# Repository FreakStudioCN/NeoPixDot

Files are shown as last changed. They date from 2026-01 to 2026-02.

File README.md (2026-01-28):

# NeoPixDot 光链像素产品说明文档

# **一、产品简介**

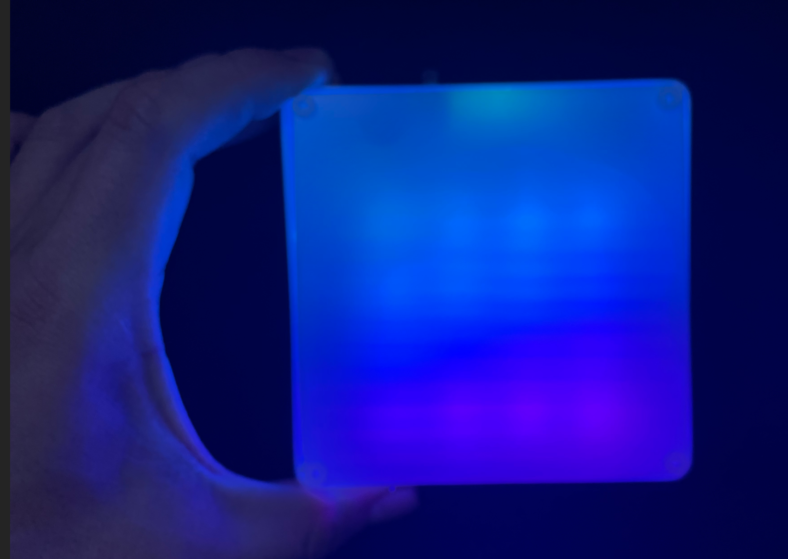
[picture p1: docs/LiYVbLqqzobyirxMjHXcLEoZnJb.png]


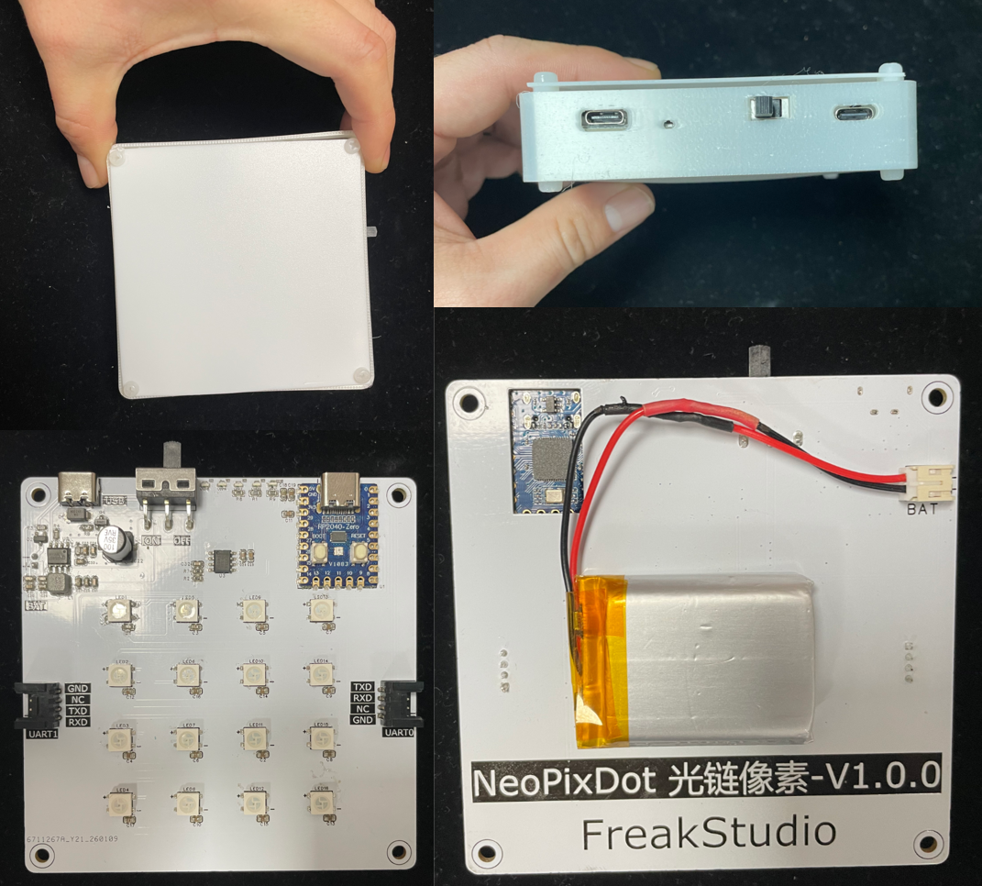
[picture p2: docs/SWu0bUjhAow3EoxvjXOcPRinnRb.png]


一款带独立供电系统的级联式 WS2812 像素模拟模块，专为解决 WS2812 协议长距离/大尺寸传输不稳定问题设计，支持脱线独立工作，可级联拼接成超大尺寸 WS2812 显示屏幕。

**仓库地址：[https://github.com/FreakStudioCN/NeoPixDot](https://github.com/FreakStudioCN/NeoPixDot)**

# **二、核心特性**

## **2.1 硬件特性**

- **主控核心**：RP2040 系列芯片，高性能且适配 MicroPython 开发
- **显示单元**：4x4 矩阵 WS2812 RGB 灯，搭配均光膜呈现“单个像素点”视觉效果
- **供电系统**：板载 IP5407 充放电单元 + 锂电池，支持 USB 充电/电池供电自动切换
- **级联设计**：双串口按“移位传输”逻辑级联，支持多模块拼接扩展

## **2.2 软件特性**

- **UART 数据处理**：解析 RGB 数据控制 WS2812 灯带，自动转发剩余数据至下一级模块
- **电池监测**：ADC 采集电池电压 + 滑动滤波算法，低电压时红灯闪烁告警并禁用 UART 控灯
- **稳定保障**：集成看门狗（WDT）定时喂狗防程序卡死，环形缓冲区 + 中断安全调度确保 UART 数据传输稳定
- **灯效支持**：正常电压下自动执行彩虹流动灯效，低电压触发红灯闪烁告警
- **调试友好**：可配置调试打印开关，计时装饰器辅助性能分析

# **三、硬件说明**

# **四、软件说明**

## **4.1 核心功能逻辑**

1. **UART 级联传输**：主控发送全量像素数据，模块解析自身 RGB 信息后，转发剩余数据至下一级
2. **电池电压监测**：100ms 周期采样电压，5 次滑动滤波去噪，低电压（3.4V）时红灯闪烁，禁用 UART 控灯；电压恢复后自动解除限制
3. **看门狗保障**：5 秒超时看门狗，1 秒周期定时喂狗 + 主循环喂狗，防止程序卡死
4. **灯效控制**：上电检测电压正常则执行彩虹流动灯效，低电压触发红灯闪烁，支持 UART 解析 RGB 数据实时控灯

## **4.2 代码关键模块**

- `RingBuffer`：环形缓冲区，解决 UART 数据接收满/空歧义问题，保障中断上下文数据安全
- `read_battery_adc`：电池电压采样 + 滑动滤波，提升电压检测稳定性
- `uart_idle_callback`：UART 空闲中断回调，接收数据并调度处理逻辑
- `rainbow_flow`：彩虹流动灯效实现，长操作前手动喂狗避免看门狗超时
- `wdt_feed_callback`：看门狗喂狗回调，定时重置超时计数器

## **4.3 文件功能介绍**

| 文件名 | 核心功能说明 |
| --- | --- |
| config.py | 全局配置中心，定义所有可配置参数（波特率、ADC 阈值、灯效参数、缓冲区大小等），统一管理常量和全局变量 |
| ring_buffer.py | 实现中断安全的环形缓冲区类，解决 UART 中断接收数据的缓存问题，预留 1 字节避免满 / 空状态歧义 |
| utils.py | 通用工具函数封装，包含调试打印（可控开关）、函数计时装饰器（辅助性能分析） |
| core_protected.py | 核心业务逻辑实现，涵盖 WS2812 灯效控制、电池电压采样 / 滤波、UART 数据解析 / 转发、看门狗喂狗、中断回调等 |
| main.py | 程序入口，完成初始化（定时器 / UART / 看门狗）、上电电压检测、主循环（电压监测 / 状态切换 / 喂狗） |
| pico_mpy_uploader.py | 编译 & 上传工具，自动将非 main.py 文件编译为 mpy（节省闪存 + 提升执行效率），通过 mpremote 上传至 Pico |

# **五、使用方法**

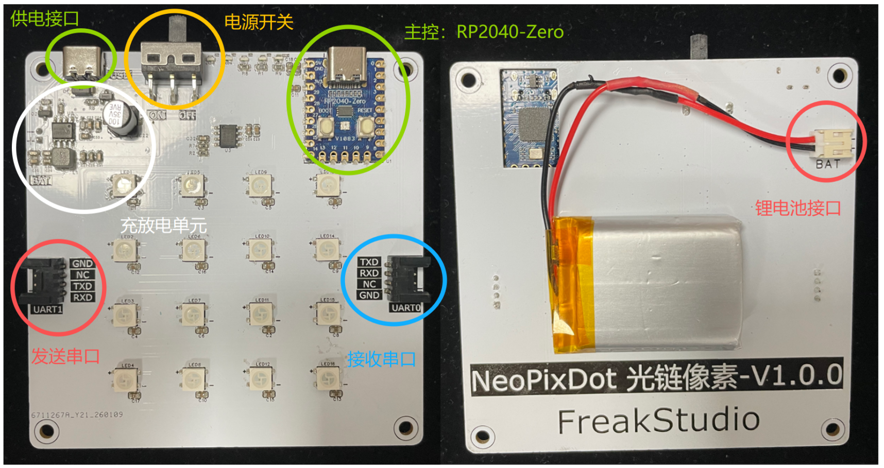
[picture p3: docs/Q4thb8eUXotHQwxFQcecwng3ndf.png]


## **5.1 供电**

- USB 充电：通过 USB 接口为锂电池充电，IP5407 自动管理充放电
- 电池供电：脱线状态下由锂电池供电，支持独立工作

正常上电情况下，有彩虹效果：

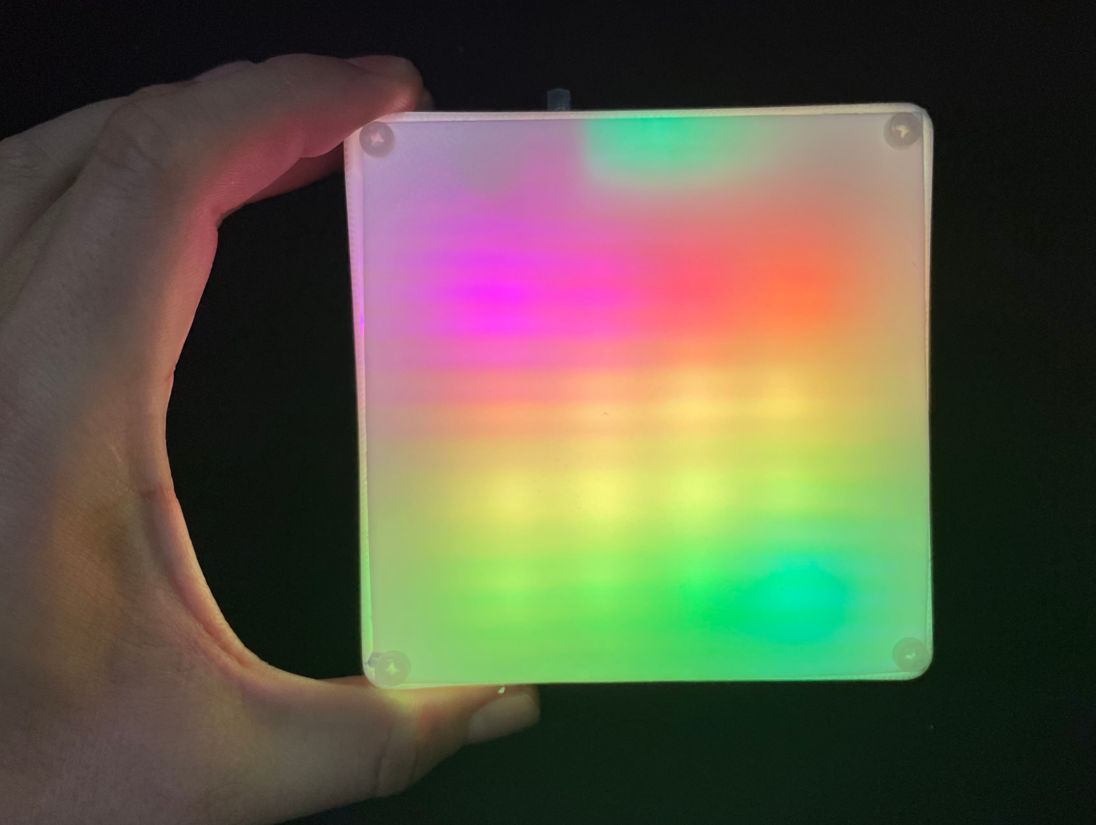
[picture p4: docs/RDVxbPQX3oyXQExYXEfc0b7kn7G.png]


**若是电量不足，则整个装置红灯闪烁。**

## **5.2 模块级联**

- 将前一级模块的 UART 转发口（UART1）连接至下一级的 UART 接收口（UART0）
- 主控发送全量像素数据，每个模块自动解析自身 RGB 数据，转发剩余数据至下一级

## **5.3 数据传输**

- UART 波特率：115200
- 数据格式：前 3 字节为当前模块 RGB 值，剩余字节为下一级模块数据
- 示例：发送 `0xFF000000FF00`，第一个模块显示红色，第二个模块显示绿色

# **六、注意事项**

1. 电池低电压阈值为 3.4V，低电时请及时充电，避免损坏电池
2. 调试模式可通过 `DEBUG_ENABLE` 开关开启/关闭，上线建议关闭以节省资源
3. 长耗时操作（如彩虹灯效、上电电压检测）会手动喂狗，避免看门狗超时重启

# 七、仓库文件介绍

# 版本记录

| **版本号** | **修改人员** | **时间** | **内容** |
| --- | --- | --- | --- |
| v1.0 | 李子圣 | 2026/01/28 | 初始化文档。 |
| | | | |
| | | | |
| | | | |

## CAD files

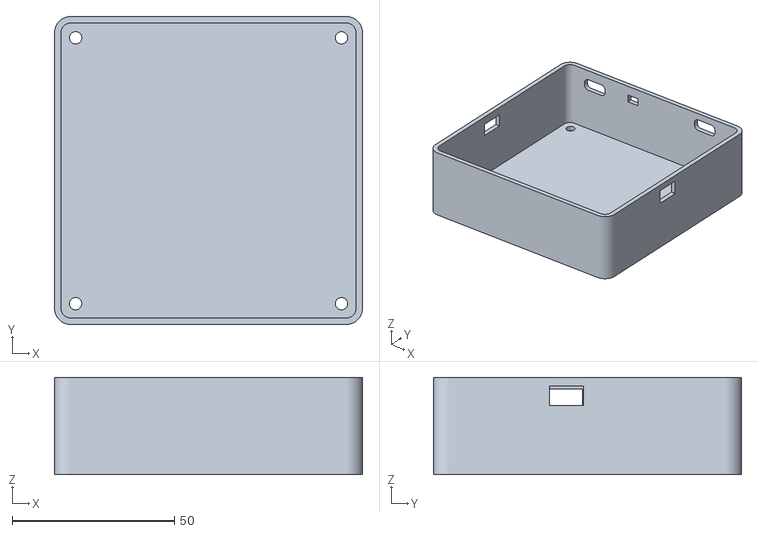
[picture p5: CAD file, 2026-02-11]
hardware/3DShell_3DShell_PCB_B.stl
95.0 x 95.0 x 30.0

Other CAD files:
hardware/DXF_LDP-ACP.SLDPRT
hardware/DXF_LDP-ACP.dxf

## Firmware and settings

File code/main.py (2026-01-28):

# Python env   : MicroPython v1.27
# -*- coding: utf-8 -*-
# @Time    : 2026/1/27 上午10:51
# @Author  : 李清水
# @File    : main.py
# @Description : 实现 UART 解析 RGB 控制 WS2812 并转发数据，
#                ADC 滑动滤波监测电池电压（低电告警禁 UART 控灯），集成 WDT 防卡死，通过环形缓冲区、中断调度保障运行稳定。

# ======================================== 导入相关模块 =========================================

from machine import UART, Pin, disable_irq, enable_irq, ADC, Timer, WDT
import time
import neopixel
import micropython
from config import *
from utils import debug_print, timed_function
from core_protected import *

# ======================================== 全局变量 ============================================

# ======================================== 功能函数 ============================================

# ======================================== 自定义类 ============================================

# ======================================== 初始化配置 ==========================================

# 分配紧急异常缓冲区（防止中断中出现异常时无法打印信息）
micropython.alloc_emergency_exception_buf(100)

# 初始化电池电压采集定时器（100ms一次）
battery_timer = Timer(-1)
battery_timer.init(period=BATTERY_TIMER_PERIOD, mode=Timer.PERIODIC, callback=read_battery_adc)

# 初始化UART接收和转发端口
uart_recv = UART(0, baudrate=BAUDRATE, tx=Pin(0), rx=Pin(1), bits=8, parity=None, stop=1)
# 配置UART空闲中断（接收完成后触发）
uart_recv.irq(handler=uart_idle_callback, trigger=UART.IRQ_RXIDLE, hard=False)
debug_print("✅ WDT initialized with timeout: %d seconds" % (WDT_TIMEOUT / 1000))

# 初始化喂狗软件定时器（1秒周期自动喂狗）
wdt_feed_timer = Timer(-1)
wdt_feed_timer.init(period=WDT_FEED_PERIOD, mode=Timer.PERIODIC, callback=wdt_feed_callback)
debug_print("✅ WDT feed timer initialized with period: %d seconds" % (WDT_FEED_PERIOD / 1000))

# ========================================  主程序  ===========================================

if __name__ == "__main__":
    debug_print("=== UART+WS2812+Battery Monitor ===")
    debug_print("UART Baudrate: %d" % BAUDRATE)
    debug_print("WS2812: GP%d, %d LEDs" % (WS2812_PIN, WS2812_NUM))
    debug_print("Battery ADC: GP%d, Threshold: %.1fV, Sliding Window: %d samples" % (
    BATTERY_ADC_PIN, LOW_VOLTAGE_THRESHOLD, WINDOW_SIZE))
    debug_print("RingBuffer: Size=%d bytes, Usable=%d bytes (reserved 1 byte for full/empty distinguish)" % (
    RING_BUFFER_SIZE, RING_BUFFER_SIZE - 1))
    debug_print("Debug Mode: %s" % ("Enabled" if DEBUG_ENABLE else "Disabled"))

    # 上电电压检测
    avg_voltage = power_on_battery_check()
    if avg_voltage < LOW_VOLTAGE_THRESHOLD:
        low_battery_flag = True
        debug_print("⚠️ Low Battery! (Avg: %.2fV < %.1fV) → Red LED On" % (avg_voltage, LOW_VOLTAGE_THRESHOLD))
        set_ws2812_color(255, 0, 0)
    else:
        low_battery_flag = False
        debug_print("✅ Battery Normal (Avg: %.2fV) → Rainbow Flow" % avg_voltage)
        rainbow_flow()

    # 初始化上一次状态
    prev_low_battery = low_battery_flag
    flash_count = 0

    # 主循环
    debug_print("\n=== Battery Voltage Monitor (Sliding Filter) ===")
    while True:
        # 打印实时电压和5次平均电压（每500ms一次）
        if flash_count % 5 == 0:
            avg_volt = get_battery_avg_voltage()
            debug_print("Battery Voltage - Single: %.2fV | Avg(5): %.2fV | Low Battery: %s" % (
            battery_voltage, avg_volt, low_battery_flag))

        # 1. 检测当前电压状态（基于5次滑动平均值）
        avg_volt = get_battery_avg_voltage()
        current_low_battery = avg_volt < LOW_VOLTAGE_THRESHOLD

        # 2. 低电压→正常电压 恢复逻辑
        if prev_low_battery and not current_low_battery:
            debug_print("✅ Battery Recovered! (Avg: %.2fV ≥ %.1fV) → LED Off, Restore UART Control" % (
            avg_volt, LOW_VOLTAGE_THRESHOLD))
            low_battery_flag = False  # 清除低电压标志
            set_ws2812_color(0, 0, 0)  # 关闭红灯
        # 3. 正常→低电压 告警逻辑
        elif not prev_low_battery and current_low_battery:
            debug_print("⚠️ Battery Low! (Avg: %.2fV < %.1fV) → Red LED Flash" % (avg_volt, LOW_VOLTAGE_THRESHOLD))
            low_battery_flag = True

        # 4. 低电压时红灯闪烁
        if current_low_battery:
            if flash_count % 10 < 5:
                set_ws2812_color(255, 0, 0)
            else:
                set_ws2812_color(0, 0, 0)

        # 5. 更新上一次状态（用于下一次循环对比）
        prev_low_battery = current_low_battery

        # 计数器递增
        flash_count += 1

        # 关键修改：主循环末尾补充喂狗
        wdt.feed()
        debug_print("🐶 WDT fed (main loop end)")

        time.sleep_ms(100)

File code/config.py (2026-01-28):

# Python env   : MicroPython v1.27
# -*- coding: utf-8 -*-
# @Time    : 2025/9/5 下午10:12
# @Author  : 李清水
# @File    : config.py
# @Description : 全局配置
# @License : CC BY-NC 4.0

__version__ = "0.1.0"
__author__ = "李清水"
__license__ = "CC BY-NC 4.0"
__platform__ = "MicroPython v1.27"

# ======================================== 导入相关模块 =========================================

# ======================================== 全局变量 ============================================

# 调试开关：True-输出日志，False-关闭所有打印
DEBUG_ENABLE = True
# 核心配置
BAUDRATE = 115200
RING_BUFFER_SIZE = 1024  # 固定环形缓冲区大小（实际可用size-1）
ISR_READ_BUF_SIZE = 64  # ISR预分配读取缓冲区
WDT_TIMEOUT = 5000  # 看门狗超时时间（毫秒），设置为5秒
WDT_FEED_PERIOD = 1000  # 喂狗定时器周期（毫秒），设置为1秒

# ====================== 电池电压&灯效核心配置 ======================

BATTERY_ADC_PIN = 26  # GP26（ADC0）采集电池电压（1/2分压）
BATTERY_TIMER_PERIOD = 100  # 电池电压采样定时器周期：100ms
ADC_MAX_VALUE = 65535  # ADC最大值
ADC_REF_VOLTAGE = 3.3  # ADC参考电压（V）
LOW_VOLTAGE_THRESHOLD = 3.4  # 低电压阈值（V）
POWER_ON_SAMPLE_DURATION = 1000  # 上电采样时长：1秒
POWER_ON_SAMPLE_COUNT = 10  # 1秒内采样次数（10次，每次100ms）
RAINBOW_LOOP_TIMES = 2  # 彩虹流动次数：2次
RAINBOW_TOTAL_DURATION = 100  # 彩虹总时长（越小越快）
battery_voltage = 0.0  # 单次采样电压值
battery_voltage_window = []  # 5次滑动窗口缓冲区
WINDOW_SIZE = 5  # 滑动滤波窗口大小（5次）
low_battery_flag = False  # 低电压标志
prev_low_battery = False  # 上一次电压状态（用于检测状态变化）

# ====================== 调度标志位配置  ======================

is_scheduled = False  # UART数据处理调度标志
wdt_print_scheduled = False  # 看门狗打印调度标志

# ====================== WS2812配置 ======================

WS2812_PIN = 2
WS2812_NUM = 16

# ======================================== 功能函数 ============================================

# ======================================== 自定义类 ============================================

# ======================================== 初始化配置 ==========================================

# ========================================  主程序  ===========================================

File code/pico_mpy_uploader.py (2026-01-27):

# Python env   : Python 3.12.0
# -*- coding: utf-8 -*-
# @File    : pico_mpy_uploader.py
# @Description : 极简版：编译py为mpy(排除main.py)并上传到树莓派Pico，main.py直接上传

import os
import subprocess


def main():
    # 1. 区分文件：main.py单独处理，其他py文件编译
    current_script = os.path.basename(__file__)
    all_py_files = [f for f in os.listdir(".") if f.endswith(".py") and f != current_script]
    main_file = "main.py" if "main.py" in all_py_files else None
    compile_py_files = [f for f in all_py_files if f != main_file]  # 排除main.py

    if not all_py_files:
        print("当前文件夹没有可处理的Python文件！")
        return

    # 2. 编译非main.py的py文件为mpy
    compiled_mpy = []
    if compile_py_files:
        print("=== 开始编译py文件为mpy（排除main.py）===")
        for py_file in compile_py_files:
            mpy_file = py_file.replace(".py", ".mpy")
            try:
                # 调用mpy-cross编译
                subprocess.run(
                    ["python", "-m", "mpy_cross", py_file, "-o", mpy_file],
                    check=True,
                    stdout=subprocess.PIPE,
                    stderr=subprocess.PIPE,
                    text=True
                )
                print(f"✅ 编译成功: {py_file} → {mpy_file}")
                compiled_mpy.append(mpy_file)
            except subprocess.CalledProcessError as e:
                print(f"❌ 编译失败 {py_file}: {e.stderr}")

    # 3. 上传文件到Pico
    print("\n=== 开始上传到树莓派Pico ===")
    # 先传编译后的mpy文件
    for mpy_file in compiled_mpy:
        try:
            subprocess.run(
                ["mpremote", "fs", "cp", mpy_file, ":/"],
                check=True,
                stdout=subprocess.PIPE,
                stderr=subprocess.PIPE,
                text=True
            )
            print(f"✅ 上传成功: {mpy_file}")
        except subprocess.CalledProcessError as e:
            print(f"❌ 上传失败 {mpy_file}: {e.stderr}")

    # 单独上传main.py（直接传原文件）
    if main_file:
        try:
            subprocess.run(
                ["mpremote", "fs", "cp", main_file, ":/"],
                check=True,
                stdout=subprocess.PIPE,
                stderr=subprocess.PIPE,
                text=True
            )
            print(f"✅ 上传成功（直接传py）: {main_file}")
        except subprocess.CalledProcessError as e:
            print(f"❌ 上传失败 {main_file}: {e.stderr}")

if __name__ == "__main__":
    # 检查依赖工具是否安装
    try:
        subprocess.run(["python", "-m", "mpy_cross", "--version"], check=True, stdout=subprocess.PIPE,
                       stderr=subprocess.PIPE)
        subprocess.run(["mpremote", "--version"], check=True, stdout=subprocess.PIPE, stderr=subprocess.PIPE)
    except (subprocess.CalledProcessError, FileNotFoundError):
        print("请先安装依赖工具：")
        print("pip install mpy-cross mpremote")
        exit(1)

    main()

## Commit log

2026-01-27 初始化仓库
2026-01-27 feat(NeoPixDot\code): 原main分包 (#1)
2026-01-27 feat(添加了 编译下载的py文件，修改了代码相关问题):
2026-01-28 docs(代码测试无误，仓库初步整理完毕):
    [3DShell_3DShell_PCB_B.stl, DXF_LDP-ACP.dxf]
2026-01-29 更新了 亚克力顶盖和均光板顶盖
    [DXF_LDP-ACP.SLDPRT, DXF_LDP-ACP.dxf]
